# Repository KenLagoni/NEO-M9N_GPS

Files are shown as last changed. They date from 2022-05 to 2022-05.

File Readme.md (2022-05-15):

# DIY - Ublox NEO-M9N GPS module

# Introduction
After too many bad experience with cheap clone GPS's, I wanted a reliable GPS unit which used the M9N Ublox chip and had a build in filter for removing noise on the input power (+5V). I was not able to find this so I decided to design one myself.

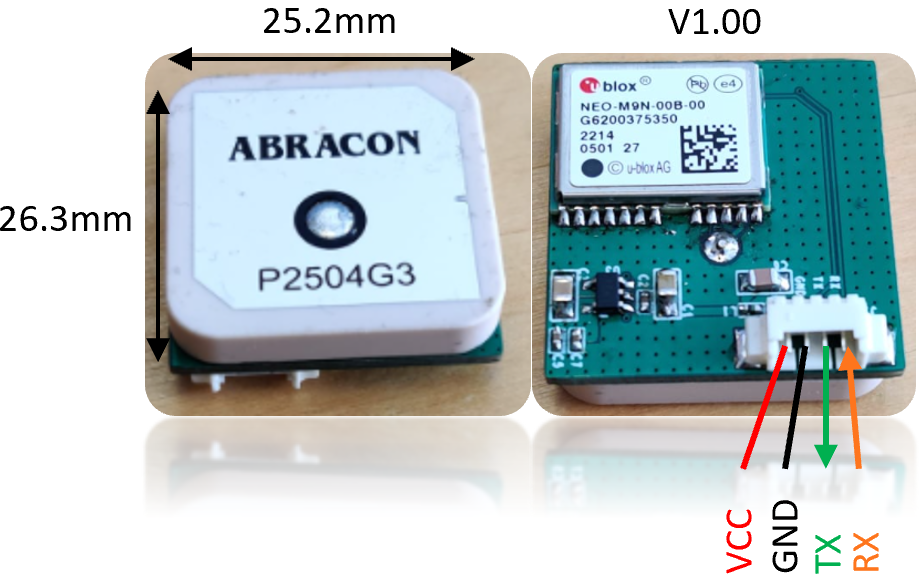
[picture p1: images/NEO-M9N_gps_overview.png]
GPS overview


# Features:
- Uses [M9N Ublox GPS module](https://content.u-blox.com/sites/default/files/NEO-M9N-00B_DataSheet_UBX-19014285.pdf).
- Build in LDO, input voltage (3.3V-5V).
- Build in EMI Low Pass Filter on power supply input (~40dB att. @ GPS frequency’s).
- Form factor of 25x25x8mm 
- Weight ~20gram.
- Price: ~$30-$40USD, when building 10pcs.

# Performance test:
## Ground test of NEO-M9N 25x25mm vs HGLRC NEO-M8N 18x18mm (using car):
Each GPS was mounted in each wing of my AR-Wing Pro and connected to the FC.
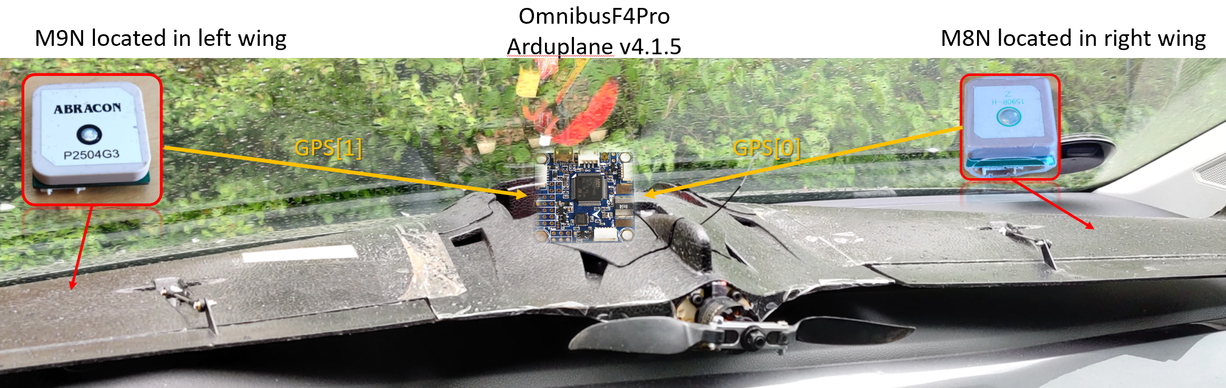
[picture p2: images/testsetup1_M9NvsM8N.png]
Ground test


---
**GPS Config**\
05/05/2022 08.59.36 : u-blox 1 HW: 00080000 SW: ROM CORE 3.01 (107888)\
05/05/2022 08.59.34 : GPS: u-blox 1 saving config\
05/05/2022 08.59.34 : u-blox 2 HW: 00190000 SW: EXT CORE 4.04 (7f89f7)\
05/05/2022 08.59.20 : GPS 2: detected as u-blox at 230400 baud\
05/05/2022 08.59.20 : GPS 1: detected as u-blox at 230400 baud

---

The Wing was placed on the dashboard of my car while I drove around. The results are:\
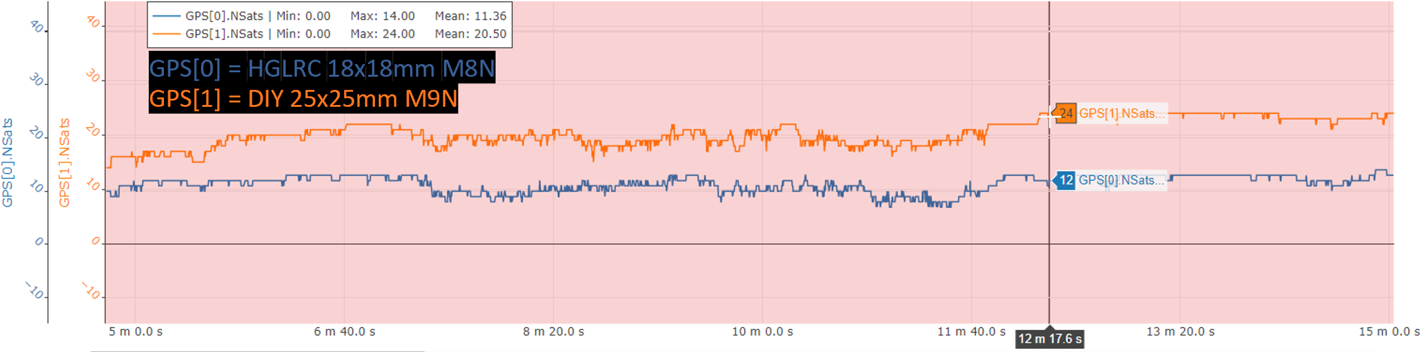
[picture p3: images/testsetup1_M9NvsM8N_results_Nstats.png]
Ground test results Nsats
\
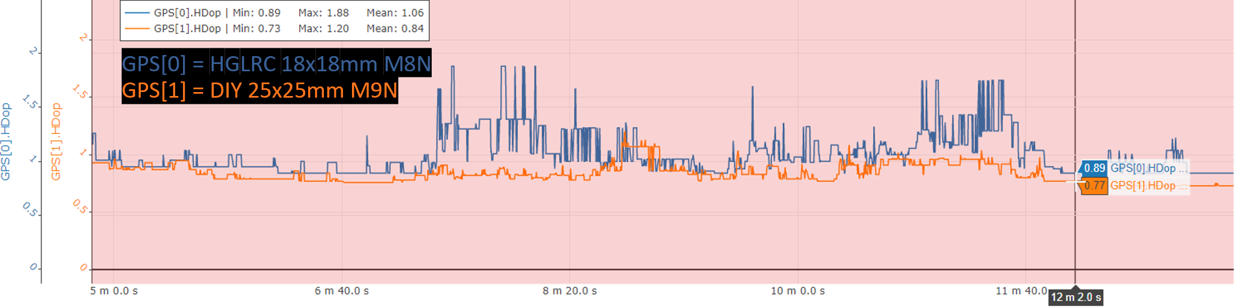
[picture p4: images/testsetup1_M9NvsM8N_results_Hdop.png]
Ground test results HDop


### Conclusion (Ground test)
The M9N with the bigger antenna and power filter out performs the M8N.

## Flight test NEO-M9N 25x25mm
The following plane was used for the test:
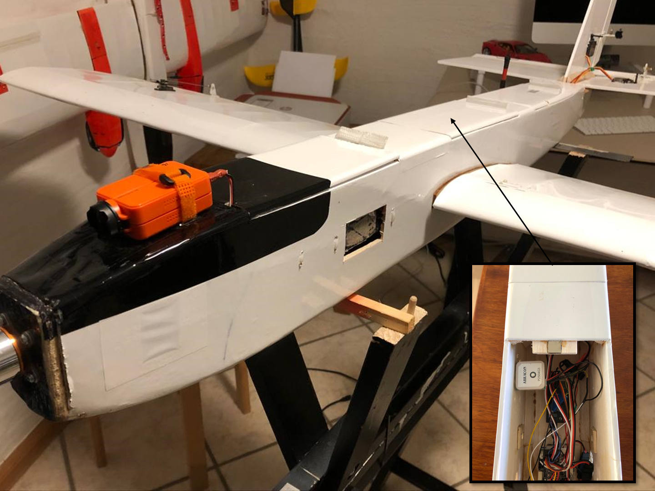
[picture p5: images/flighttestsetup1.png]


### Conclusion (flight test)
Again the M9N performed really well. Number of satellites around 27 and a Hdop around 0.6.

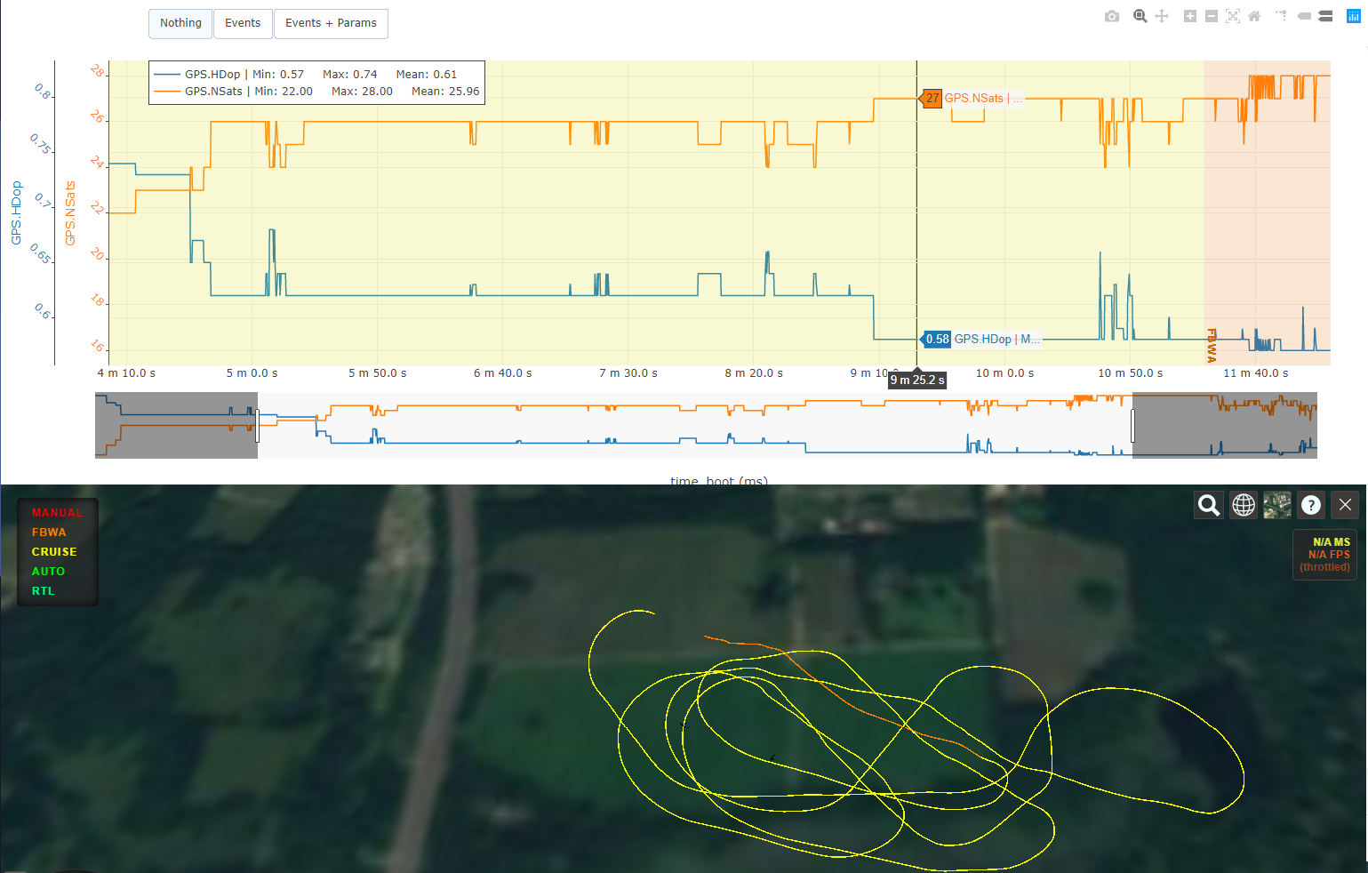
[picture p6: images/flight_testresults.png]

 
# Revision
Version V1.00 - First Release.

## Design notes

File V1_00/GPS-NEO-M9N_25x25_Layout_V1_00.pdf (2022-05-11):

PAGE | CONTENT
2 | 1_TOP
3 | 2_INNER_LAYER_2
4 | 3_INNER_LAYER_3
5 | 4_BOTTOM
6 | Silkscreen_top

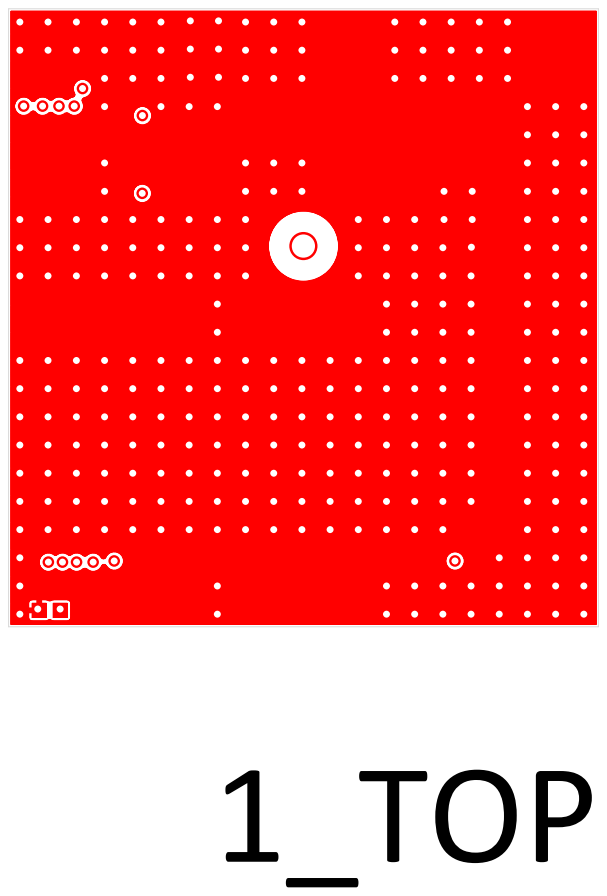
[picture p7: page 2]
1_TOP

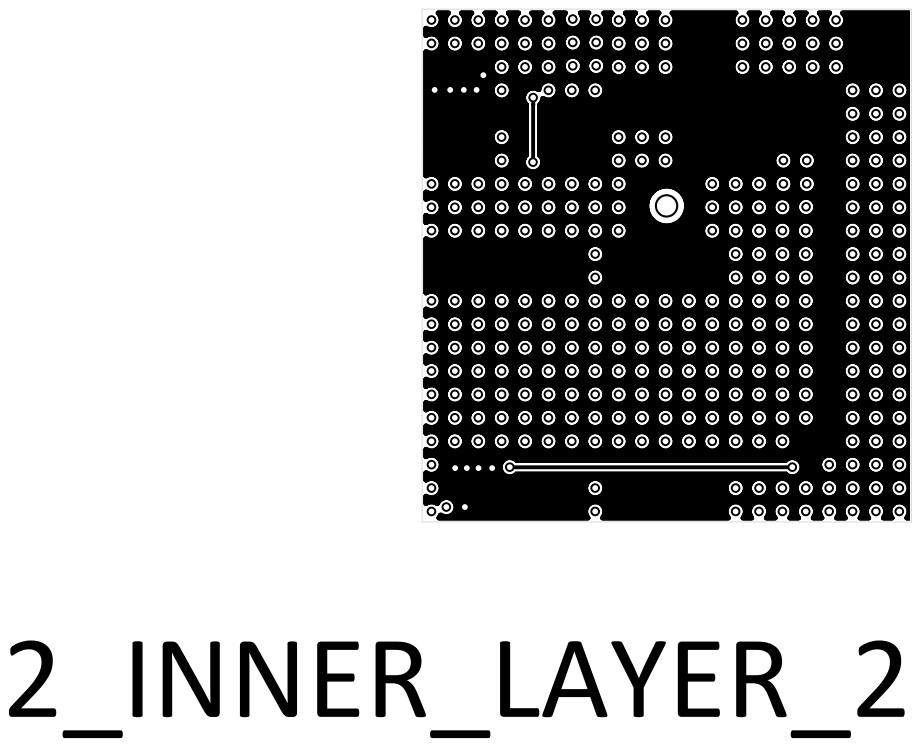
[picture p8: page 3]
2_INNER_LAYER_2

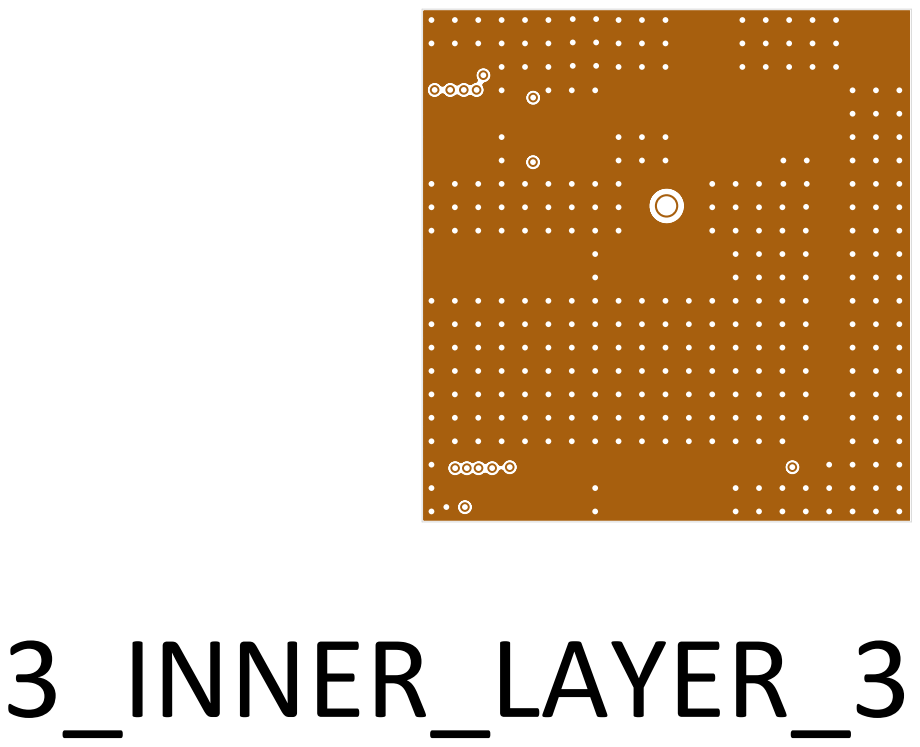
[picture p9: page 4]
3_INNER_LAYER_3

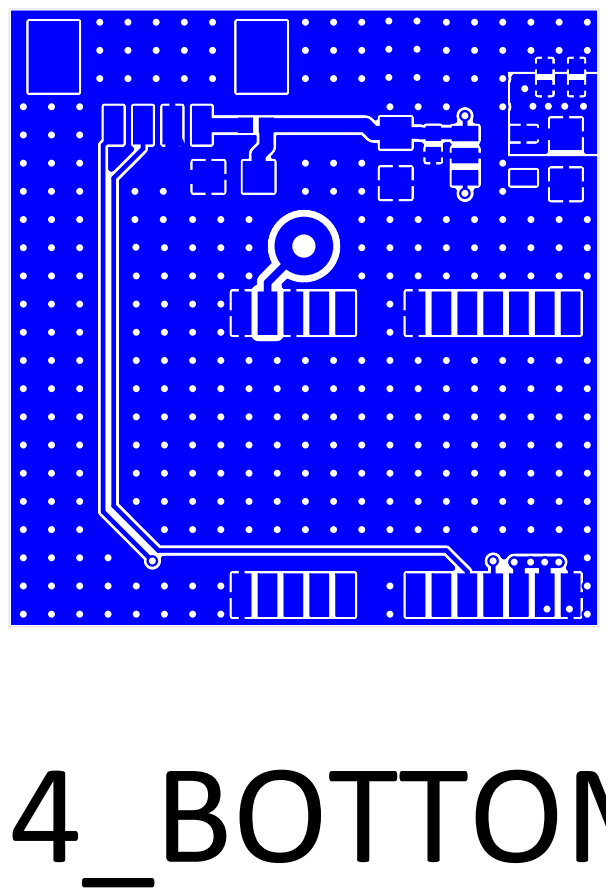
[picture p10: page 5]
4_BOTTOM

Silkscreen_top

C4

U2

Silkscreen_bot

C1

C2
C3

C5

J1

C6 | U3

L1

C7

RX
TX

GND

VCC

FIGURE | FINISHED_SIZE | TOLERANCE_DRILL | PLATED | QTY
| 0.3 | +0.05/-0.05 | PLATED | 317
| 1.0 | +0.2/-0.2 | PLATED | 1

ALL UNITS ARE IN MILLIMETERS

DRILL CHART: TOP to BOTTOM

NCLEGEND-1-4

Board_outline

Soldermask_top

Soldermask_bot

Solderpaste_top

Solderpaste_bot

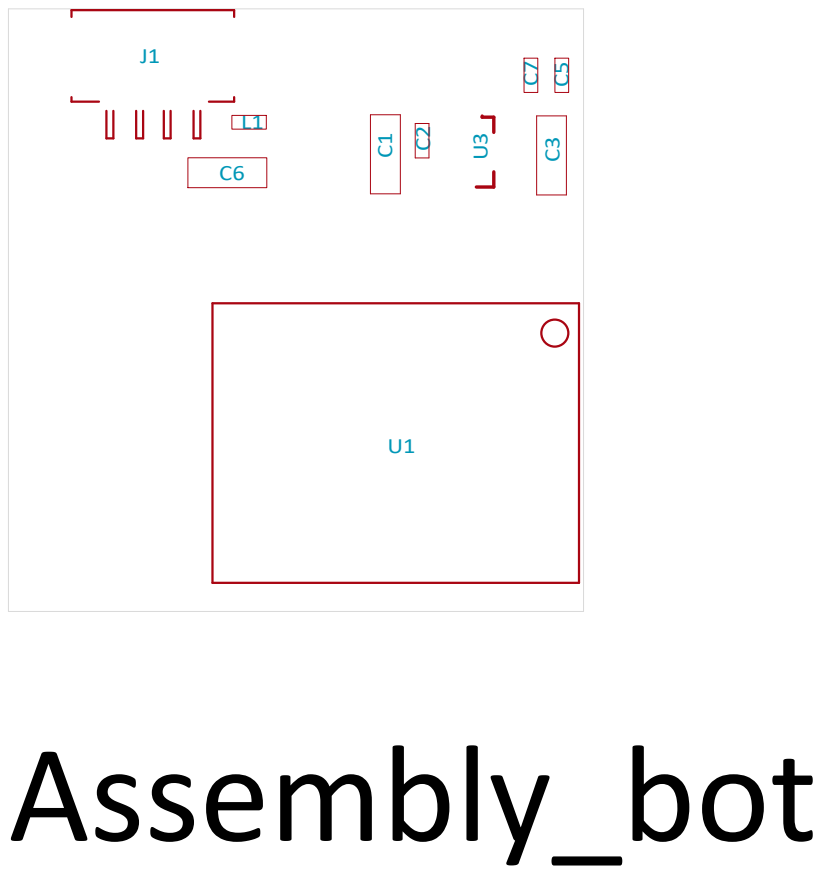
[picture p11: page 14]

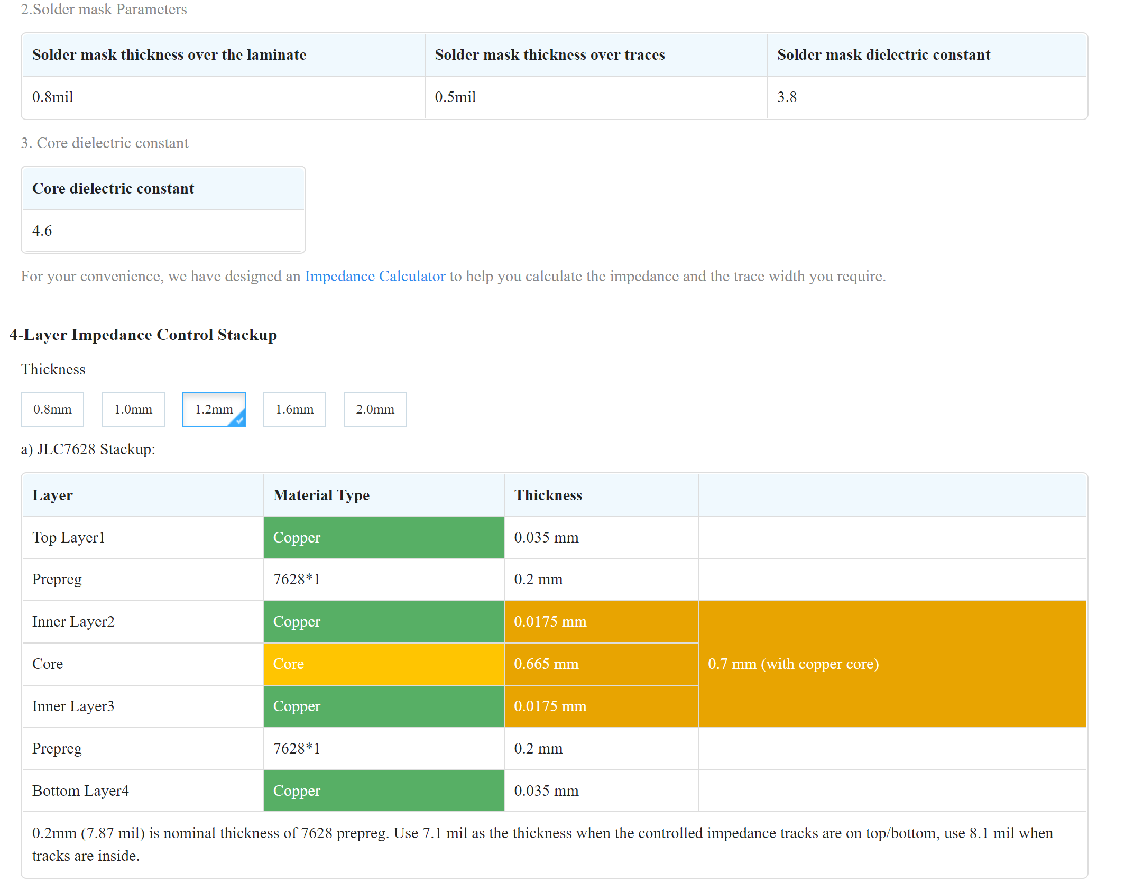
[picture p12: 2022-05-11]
V1_00/4-layer-impedance_1_2mmthick_PCB Layer Stackup-JLCPCB.png

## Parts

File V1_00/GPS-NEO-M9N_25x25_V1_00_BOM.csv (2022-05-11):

History Revised: Wednesday, Feb 02, 2022
GPS NEO-M9N Revision: 10
Bill Of Materials | Page1
Item | Quantity | Reference | Part | PCB | Manufacturer | Manufacturer PN | Farnell Part Number | Farnell Price (DKK)
______________________________________________
1 | 2 | C1,C3 | 100uF/6V3 | r_0805 | Generic | 100uF, 0805, 6V3, 20% | 2494476 | 6.35 | 12.7
2 | 3 | C2,C5,C7 | 100nF | r_0402 | Generic | 100nF, 0402, 16V 20% | 2524679 | 0.26 | 0.78
3 | 1 | C4 | 1uF | r_0402 | Generic | 1uF, 0402, 16V 20% | 2821149 | 0.437 | 0.437
4 | 1 | C6 | 180pF | r_0805 | Johanson Technology | 251R15S181JV4E | 1885453 | 2.36 | 2.36
5 | 1 | J1 | 4x1_1.25mm Molex Picoblade | r_conn_molex53261-4P-1_25H | Molex | 53261-0471 | 1125374 | 3.98 | 3.98
6 | 1 | L1 | 6.8nH | r_0402 | MURATA | LQG15HN6N8J02D | 1343077 | 0.416 | 0.416
7 | 1 | U1 | UBLOX NEO-M9N | r_ublox_neo | UBLOX | NEO-M9N-00B | Mouser (377-NEO-M9N-00B) | 191.61 | 191.61
8 | 1 | U2 | APARM2504 25x25x4mm RHCP | l_gps_APARM2504_25x25x4 | ABRACON | APARM2504-SG3 | 3228317 | 29.61 | 29.61
9 | 1 | U3 | LDLN025M33R | r_sot23-5pin | ST | LDLN025M33R | 2851941 | 5.36 | 5.36

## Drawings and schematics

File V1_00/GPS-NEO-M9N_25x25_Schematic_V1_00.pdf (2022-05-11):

Revision | History | Responsible

# REVISION 1.00

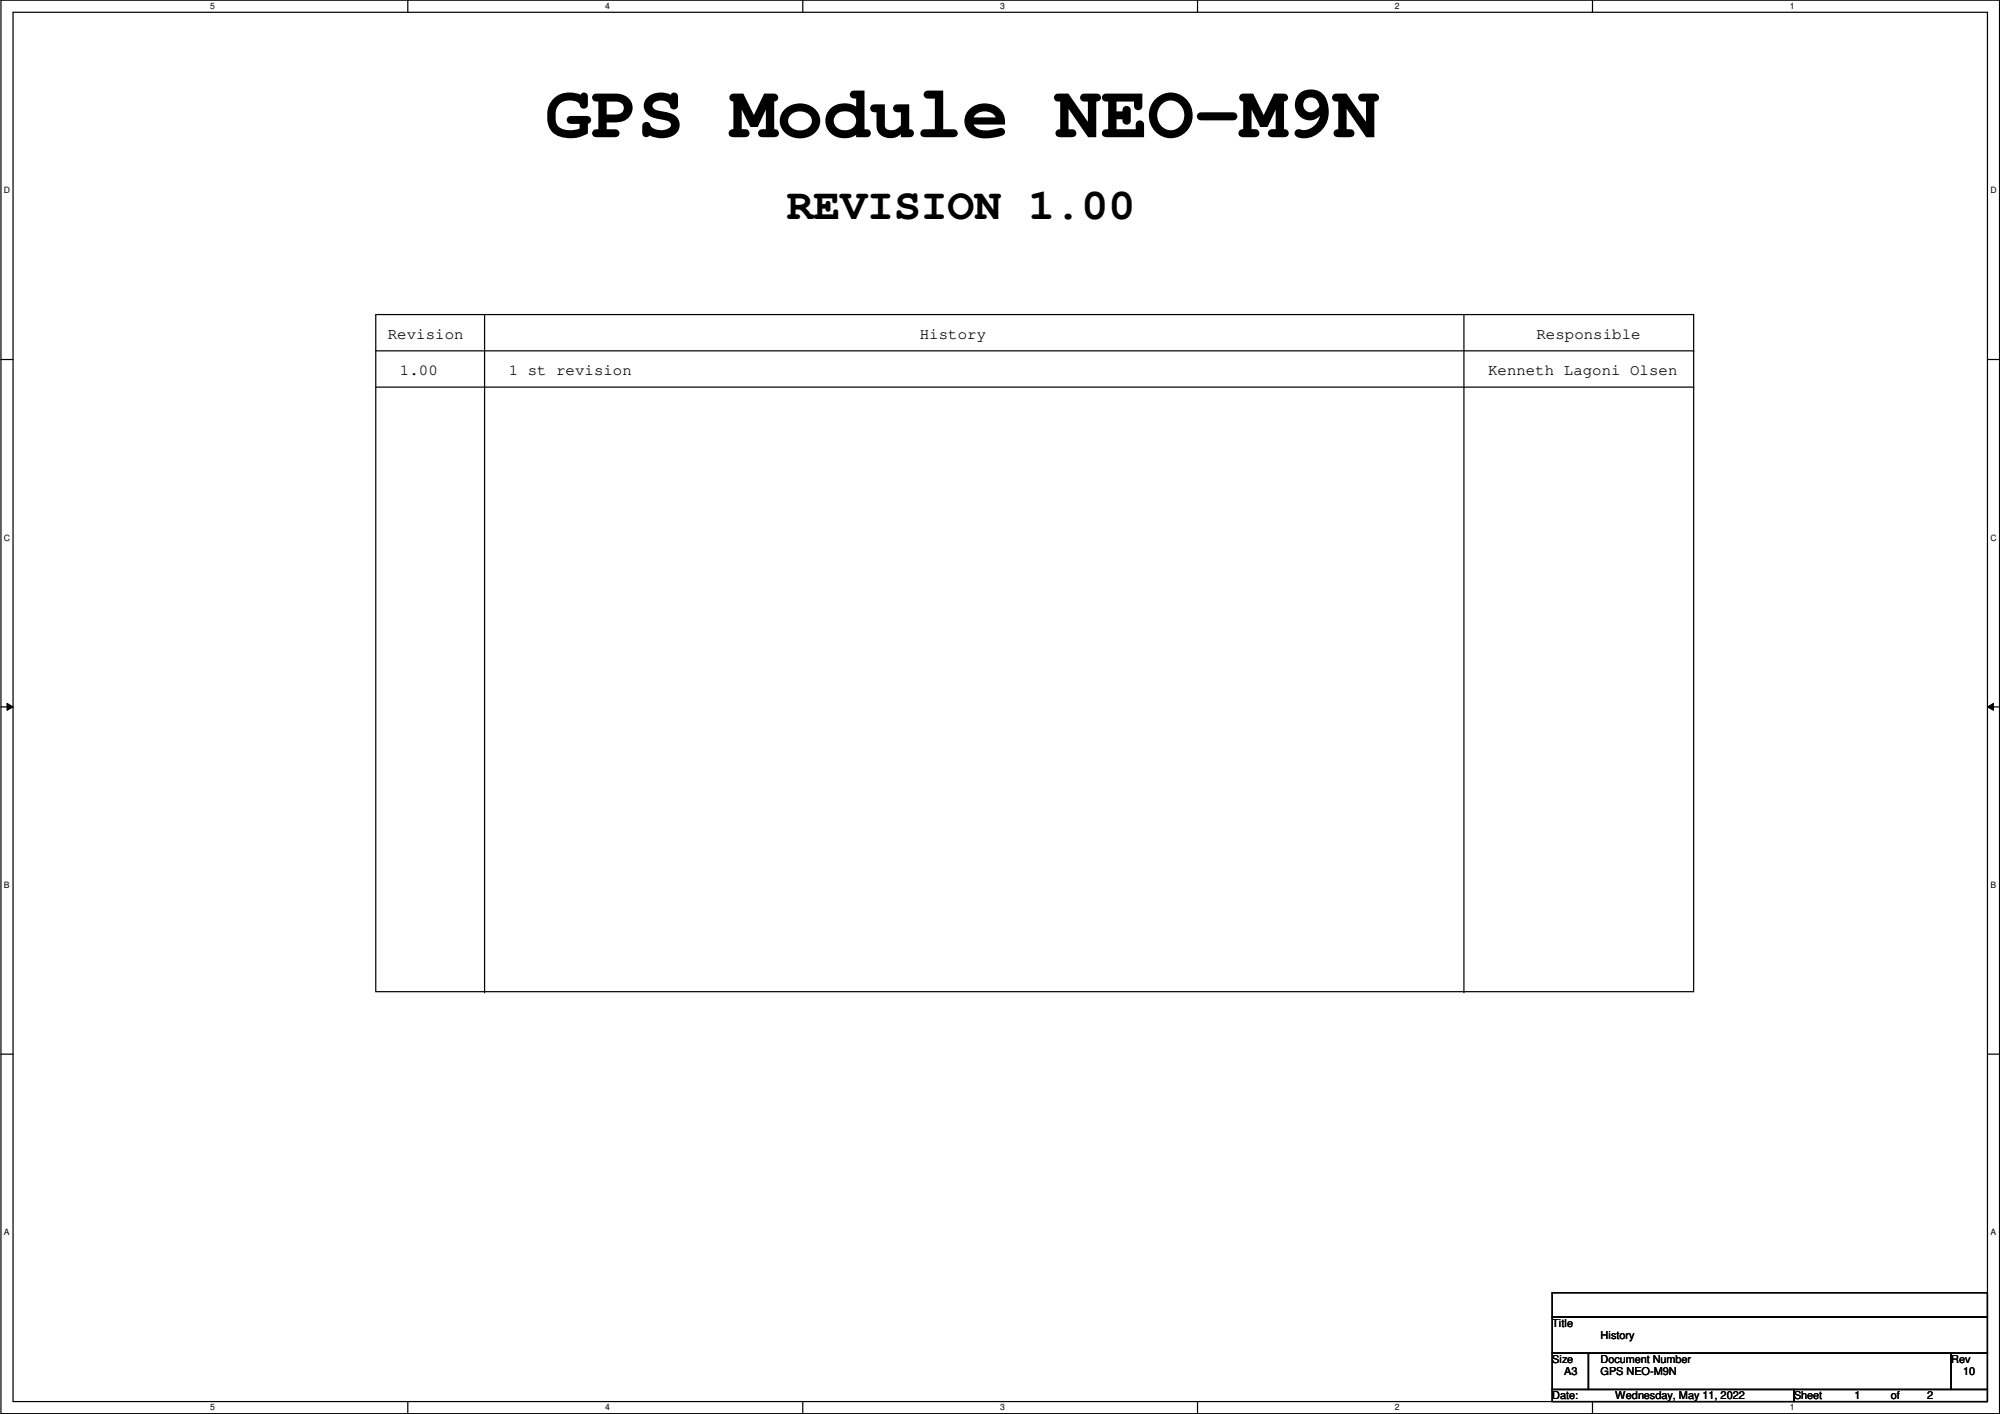
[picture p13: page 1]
1 st revision; Kenneth Lagoni Olsen; Title; Size; Document Number; Rev; Date:; Sheet; GPS NEO-M9N; History; Wednesday, May 11, 2022

GPS Module NEO-M9N

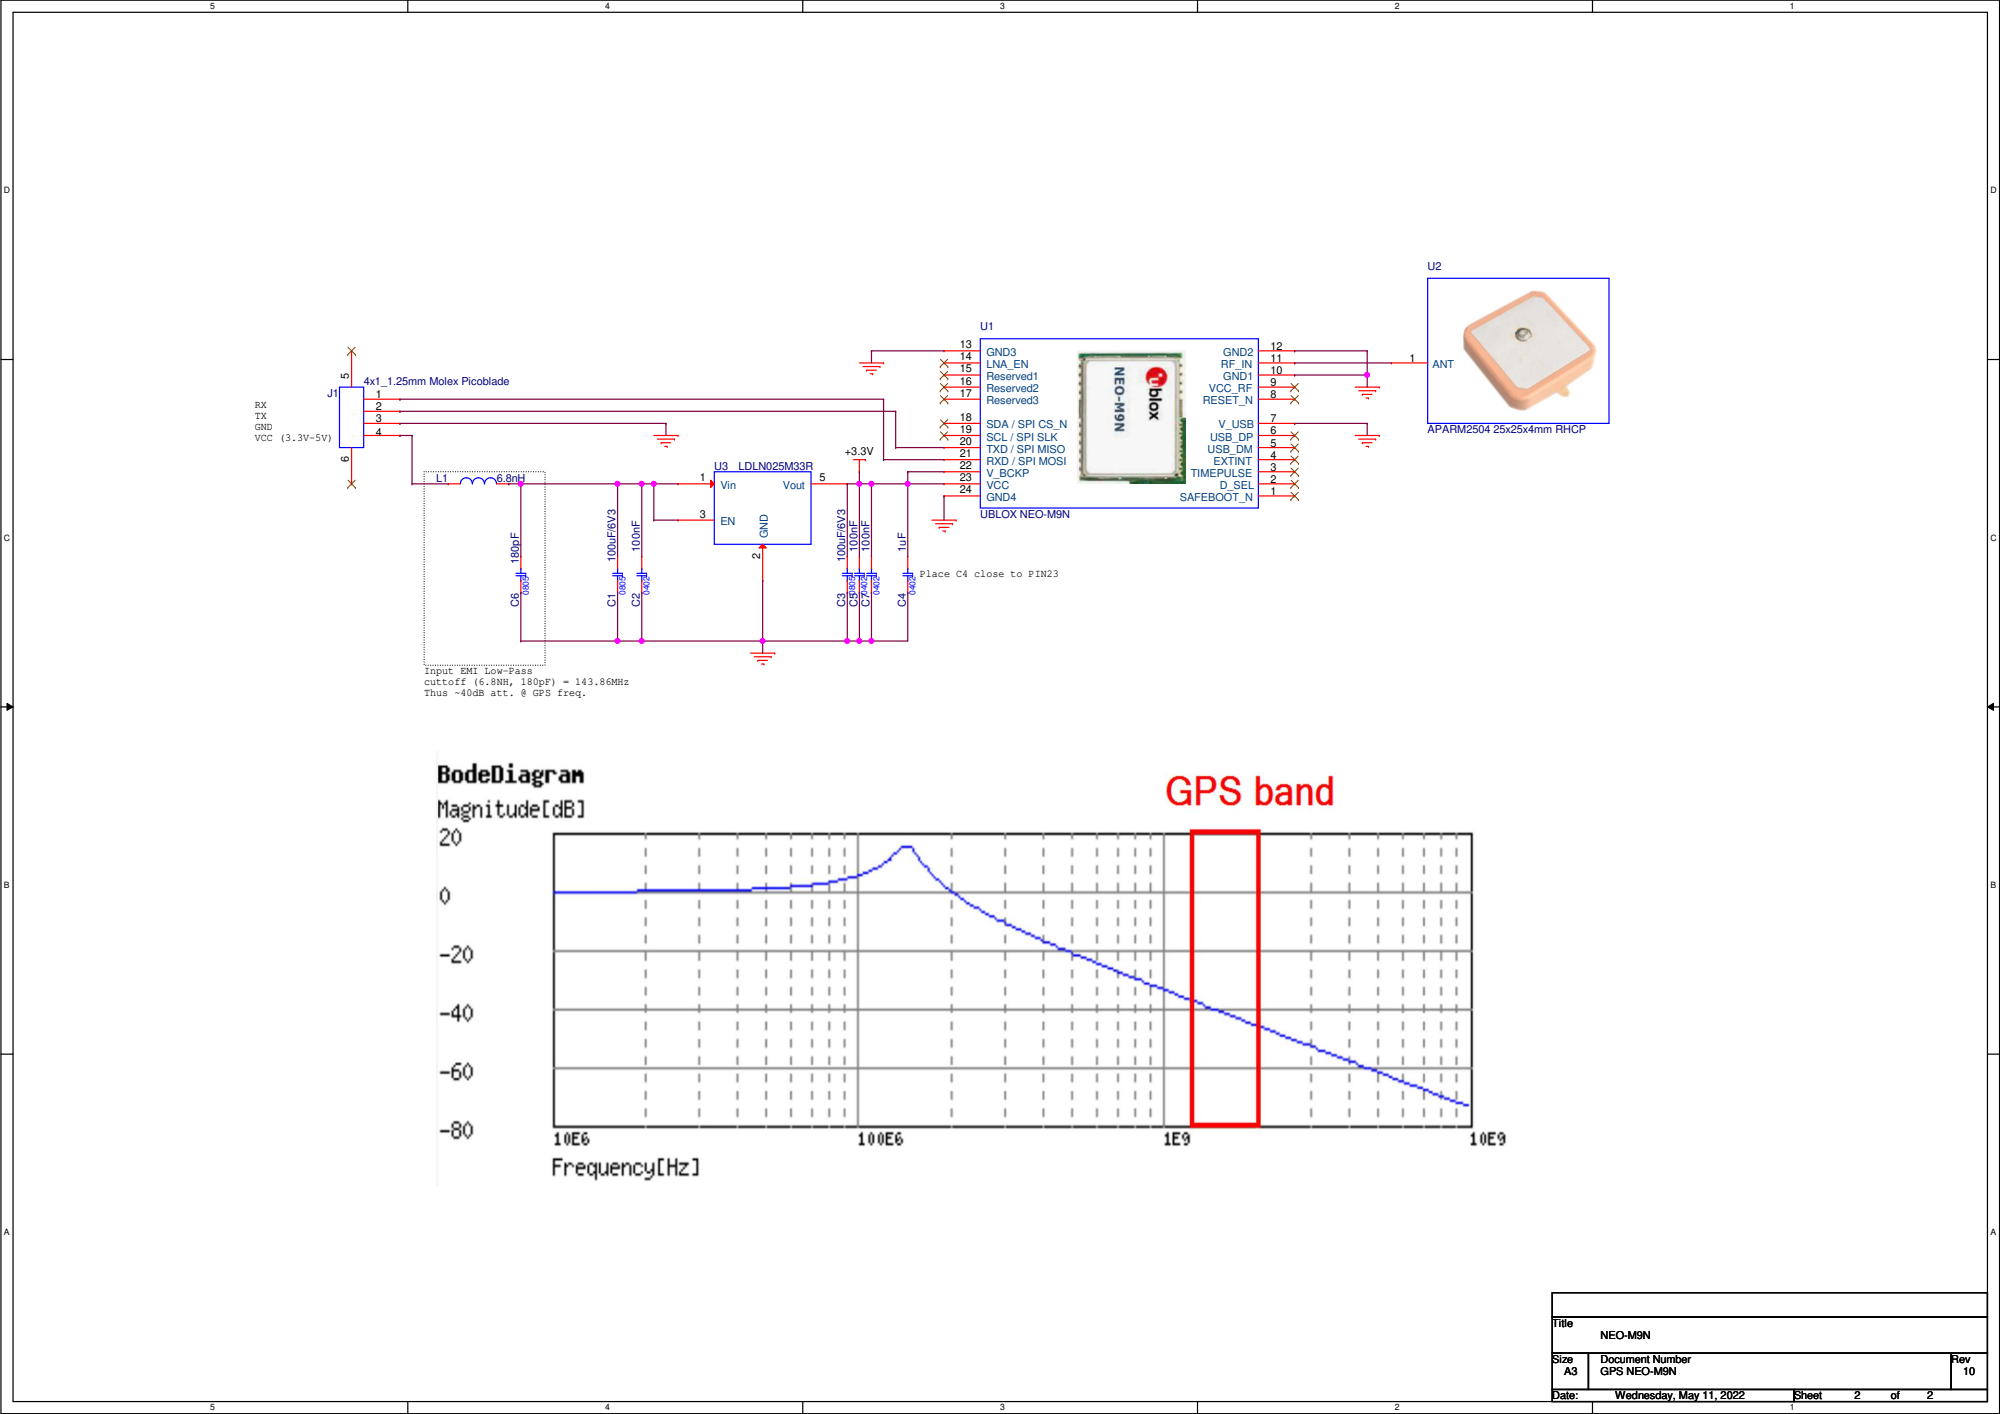
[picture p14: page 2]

Input EMI Low-Pass
cuttoff (6.8NH, 180pF) = 143.86MHz
Thus ~40dB att. @ GPS freq.
